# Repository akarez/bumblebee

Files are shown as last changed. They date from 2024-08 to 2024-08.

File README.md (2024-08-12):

<h1 align="center">bumblebee</h1>

<p align="center">
    The bumblebee is a wireless mechanical keyboard PCB designed as a drop-in replacement for the RAMA M6. It features the nRF52840 SoC, nPM1300 power management IC, and a 2.4GHz chip antenna. The keymaps can be configured with ZMK and GitHub actions.
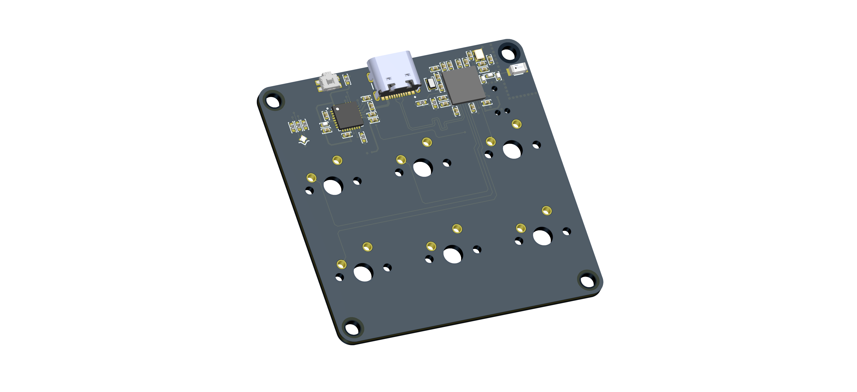
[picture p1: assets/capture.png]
bumblebee 3D render
    
</p>

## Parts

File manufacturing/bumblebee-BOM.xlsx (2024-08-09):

Comment | Designator | Footprint | JLCPCB Part # | Manufacturer Part #
AMCA31-2R450G-S1F-T3 | A1 | FP-AMCA31-MFG | C3283994 | AMCA31-2R450G-S1F-T3
1µF | C1, C2, C11, C20 | CAP 0402_1005 | C157353 | 0402X105K100NT
10µF | C3, C4, C6 | CAP 0402_1005 | C2846677 | 0402X106M100NT
2.2µF | C5 | CAP 0402_1005 | C60078 | 0402X225M100NT
0.1µF | C7, C12, C13, C14, C16 | CAP 0402_1005 | C301997 | 0402X104K160CT
18pF | C8, C15 | CAP 0402_1005 | C126499 | GCM1555C1H180JA16D
4.7µF | C9, C10, C23 | CAP 0402_1005 | C167656 | 0402X475M100NT
100pF | C18 | CAP 0402_1005 | C343043 | C1005NP01H101JT000F
8pF | C22, C24 | CAP 0402_1005 | C130118 | CC0402CRNPO9BN8R0
Red, Green, Blue (RGB) | D1 | Citizen CL-505S-X-SD-T | C2962089 | MHPA1010URGBCT
T1M-02-T-SH-L-K | J2 | SAMTEC_T1M-02-T-SH-L-K | C160402 | SM02B-SRSS-TB(LF)(SN)
2.2 µ | L1 | IND 0402_1005 | C383389 | MLZ1005M2R2WT000
8.3 n | L2 | IND 0402_1005 | C412363 | LQW15AN8N3C10D
9.7 n | L4 | IND 0402_1005 | C408684 | SDWL1005C9N7JSTFM01
0R | R1, R2, R3 | RES 0402_1005 | C176107 | QR0402J0R00Q10Z
300 k | R5 | RES 0402_1005 | C881154 | CR0402J300KQ10Z
10 k | R6, R7, R8 | RES 0402_1005 | C881209 | CR0402F10K0Q10Z
PTS840 GK SMTR LFS | SW7 | EVQP7A_J_B_K | C221907 | PTS840GKSMTRLFS
NPM1300-QEAA-R | U1 | Nordic_QFN50P500X500X90-33N | C7466043 | NPM1300-QEAA-R
NRF52840-QIAA-R | U2 | NRSC-AQFN-73 | C190794 | NRF52840-QIAA-R
32.768 kHz | Y1 | ABRACON ABS06 | C1985397 | ABS06-32.768KHZ-1-T
32MHz | Y2 | BT-XTAL_2016 | C914155 | XRCGB32M000F1H01R0

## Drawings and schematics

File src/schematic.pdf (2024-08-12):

# USB & POWER

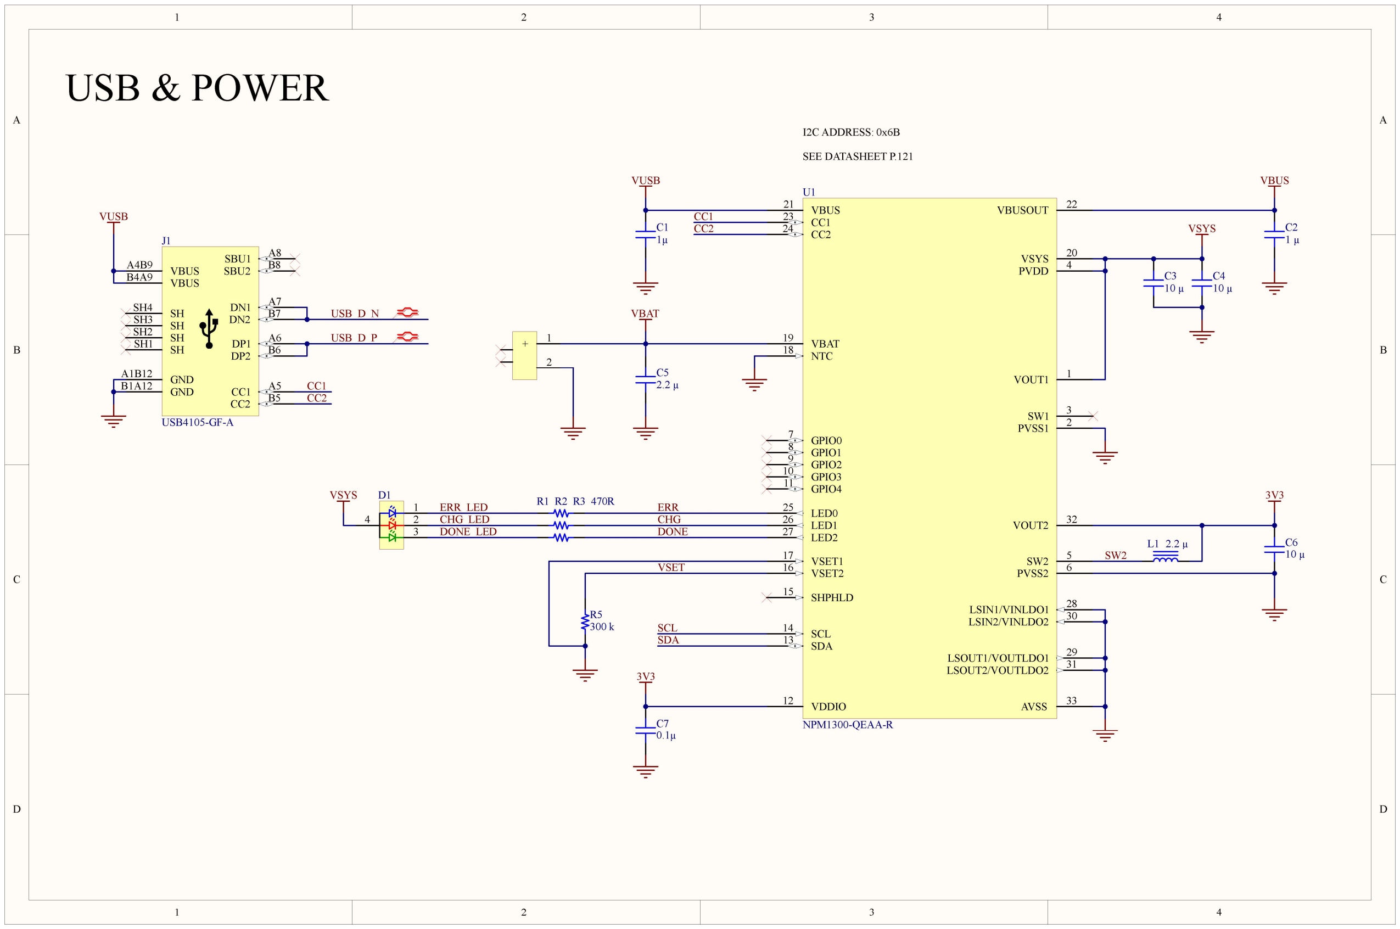
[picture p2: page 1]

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
USB_D_N

USB_D_P

CC1 | A5
DP1 | A6
DN1 | A7
SBU1 | A8
VBUS A4B9
VBUS B4A9
CC2 | B5
DP2 | B6
DN2 | B7
SBU2 | B8

GND A1B12
GND B1A12
SH SH1 | SH SH2 | SH SH3 | SH SH4

J1

USB4105-GF-A

ERR
CHG

I2C ADDRESS: 0x6B

SEE DATASHEET P.121

VBUS 21

VSYS 20

VBAT 19

AVSS | 33
VBUSOUT | 22

LED0 25
LED1 26
LED2 27

CC1 23
CC2 24

NTC 18

SHPHLD 15

GPIO0 7
GPIO1 8
GPIO2 9
GPIO3 10
GPIO4 11

VDDIO 12

SCL 14
SDA 13
PVDD | 4
SW1 | 3
VOUT1 | 1
VSET1 17 | SW2 | 5
| VOUT2 | 32

VSET2 16

PVSS1 | 2
PVSS2 | 6
LSIN1/VINLDO1 | 28
LSIN2/VINLDO2 | 30
LSOUT1/VOUTLDO1 | 29
LSOUT2/VOUTLDO2 | 31

U1

NPM1300-QEAA-R

SCL
SDA

VBAT

### 2.2 µ

C5

VBUS

### 10 µ

C4

VSYS

1
4 2
3

D1

DONE

VSYS

VSET

### 10 µ

C6

3V3

3V3

+

1

2

VUSB

VUSB

CC1
CC2

CC1
CC2

SW2

1µ

C1

### 1 µ

C2

300 k

R5

0.1µ

C7

### 10 µ

C3

L1 2.2 µ

ERR_LED
CHG_LED
DONE_LED

R1 R2 R3 470R

# nRF52840

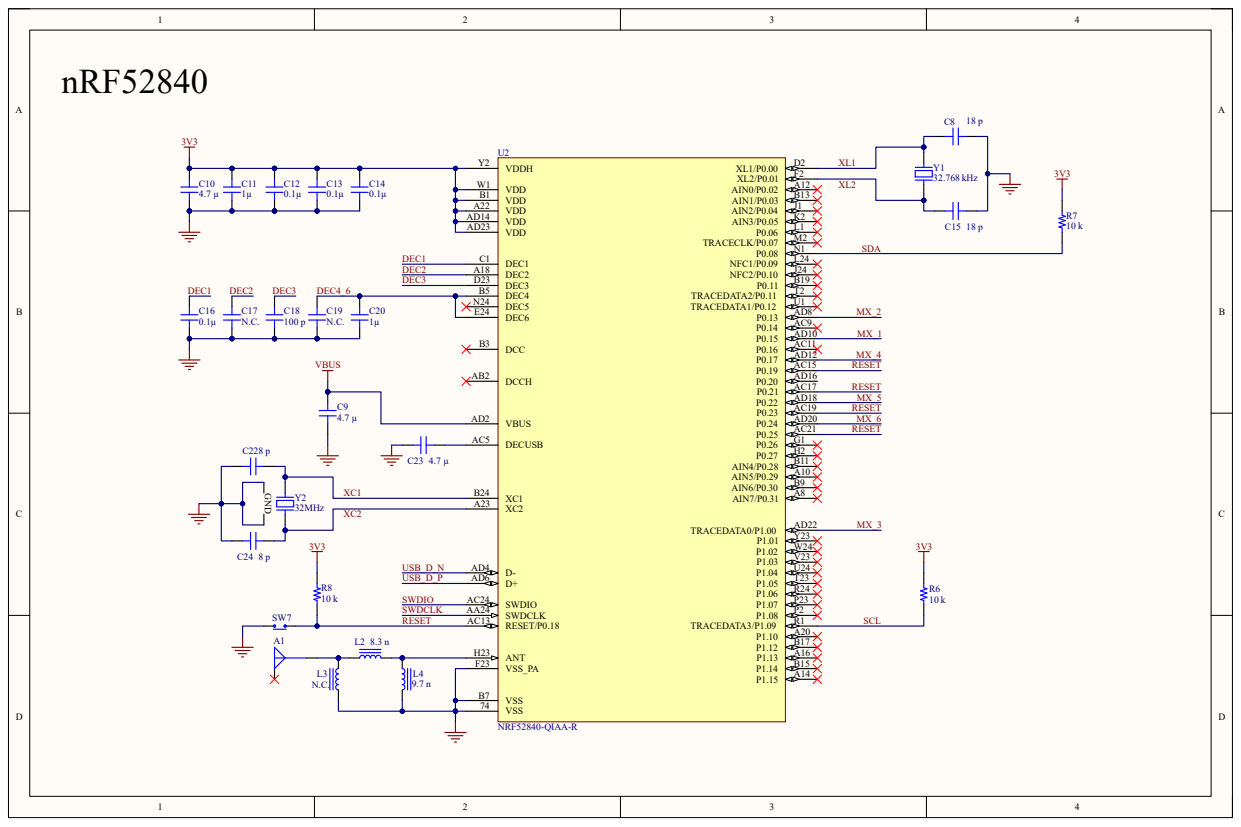
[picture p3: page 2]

# PERIPHERALS

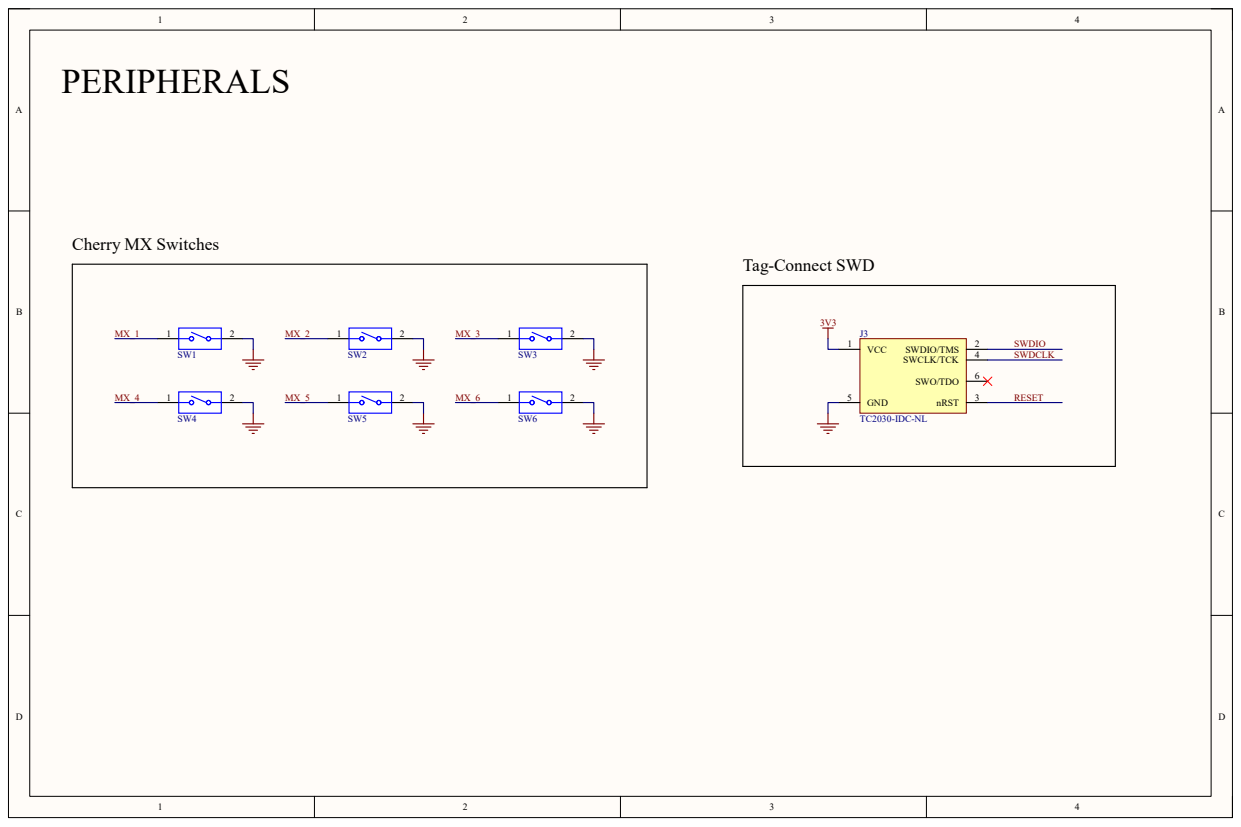
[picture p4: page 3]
VCC 1; SWDIO/TMS; nRST; SWCLK/TCK; GND 5; SWO/TDO; TC2030-IDC-NL; SWDIO SWDCLK; RESET

Cherry MX Switches

Tag-Connect SWD

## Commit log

2023-04-05 updated component placement
    [Bumblebee.PcbDoc, Bumblebee.SchDoc]
2023-08-15 reduced switch count
    [Bumblebee.PrjPcb]
2023-12-26 update MCU, add battery charging and LDO
    [Bumblebee.PcbDoc, Bumblebee.SchDoc, bumblebee.PcbDoc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]
2023-12-29 final revision
    [bumblebee.PcbDoc, bumblebee.PrjPcb, bumblebee.SchDoc]
2023-12-29 add fabrication files
    [Bumblebee-BOM.csv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]
2024-01-10 fix: updated component footprints
    [bumblebee.PcbDoc, bumblebee.PrjPcb, bumblebee.SchDoc]
2024-01-10 final REV-A
    [Bumblebee-CPL.csv]
2024-05-18 initial rev b
    [Bumblebee-BOM.csv, bumblebee 2.0.PrjPcb, bumblebee.PcbDoc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]
2024-07-24 breakup schematic pages
    [1_power.SchDoc, 2_mcu.SchDoc]
2024-07-24 update board outline matching RAMA M6 case
    [bumblebee 2.0.PrjPcb, bumblebee.PcbDoc]
2024-07-31 finished initial routing
    [1_power.SchDoc, 2_mcu.SchDoc, bumblebee.PcbDoc]
2024-08-08 update Z net and finish routing
    [1_power.SchDoc, 2_mcu.SchDoc, bumblebee 2.0.PrjPcb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]
2024-08-08 final cleanup
    [1_power.SchDoc, 3_peripherals.SchDoc, bumblebee 2.0.PrjPcb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]
2024-08-09 replace led
    [1_power.SchDoc, bumblebee 2.0.PrjPcb, bumblebee.PcbDoc]
2024-08-09 add manufacturing data
    [Bumblebee-BOM.csv, bumblebee-BOM.xlsx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]
2024-08-12 update led resistor value
    [1_power.SchDoc, bumblebee 2.0.PrjPcb, bumblebee.PcbDoc]
2024-08-12 upload pdf schematic
